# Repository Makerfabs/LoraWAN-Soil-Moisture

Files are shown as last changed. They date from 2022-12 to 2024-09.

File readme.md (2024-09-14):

# LoraWAN Soil Moisture

```c++
/*
Version:		V1.2
Author:			Vincent
Create Date:	2022/12/15
Note:
	2022/12/30	V1.2	:Update readme
	2022/12/16 	V1.1	:Fix adc3 read error.
*/
```


[toc]

# Makerfabs

[Makerfabs home page](https://www.makerfabs.com/)

[Makerfabs Wiki](https://wiki.makerfabs.com/)

# LoraWAN Soil Moisture
## Intruduce

Product Link ：[LoRaWAN Temperature/ Humidity/ Soil Moisture Sensor](https://www.makerfabs.com/lorawan-temperatur-humidity-soil-moisture-sensor.html) 

Wiki Link : [LoRaWAN Temperature/ Humidity Soil Moisture Sensor](https://wiki.makerfabs.com/LoRaWAN_Temperature_Humidity_Soil_Moisture_Sensor.html) 

This module monitor soil moisture via capacitive method, with waterproof coating, it avoids the corrosion problem that usually happens on cheap resistor-mode soil moisture sensor. There is also onboard AHT10 -air temperature/ humidity sensor, to monitor air status, proper for usage in the greenhouse. This module uses 3x AAA battery as power, with sleep current of 26uA and working current of 4mA, the average working time can be more than 1 year. (with 1-hour message interval, Class A ).

## Feature

- LoRaWAN Nodes, RA08H
- Soil Moisture Measurement based on capacitive Testing
- Low power: 7.1uA when sleeping/4mA in message sending turn around
- Onboard AHT10 sensor to monitor air temperature and air humidity
- Onboard Battery Voltage Measurement
- Full Open Source- all hardware and software open at GitHub
- Compatible with Arduino
- Supply power voltage: 4.7~3.5V

### Front:

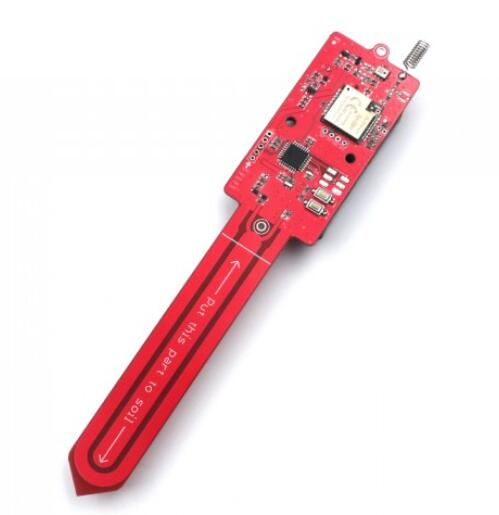
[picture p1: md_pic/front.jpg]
front


### Back:
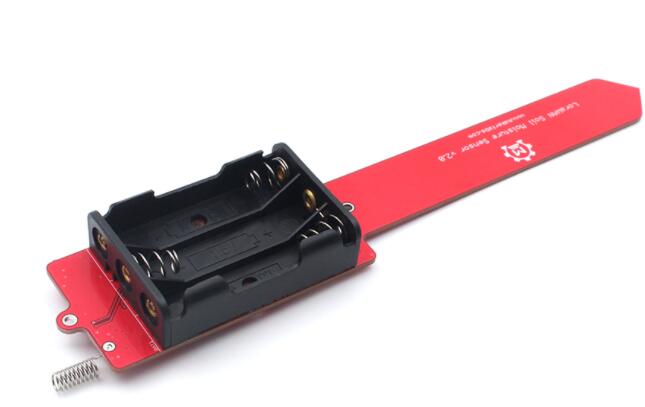
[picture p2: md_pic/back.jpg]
back


# Code

## Compiler Options

**If you have any questions，such as how to install the development board, how to download the code, how to install the library. Please refer to :[Makerfabs_FAQ](https://github.com/Makerfabs/Makerfabs_FAQ)**

- Open code with Arduino IDE
- Set Lorawan config in code.
- Upload codes, select "Arduino Pro or Pro Mini" and "3.3V 8MHz"

## Uploader

There is no USB socket or integrated serial port chip on some modules. But there are serial ports: VCC, GND, RX, TX, DTR. 

There are two ways to connect a serial port.

### MakerFabs CP2104 USB2UART

Product link : [CP2104 USB2UART](https://www.makerfabs.com/cp2104-usb-to-serial-converter.html)

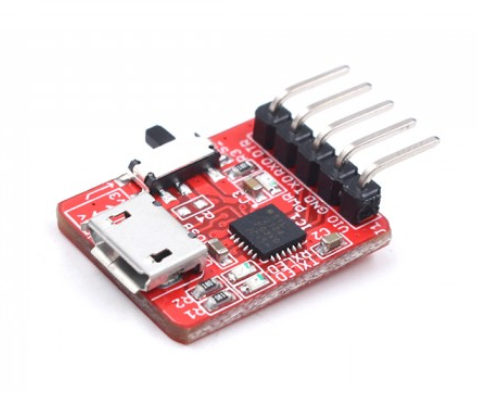
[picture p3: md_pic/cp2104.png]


This CP2104 USB to Serial Converter is super tiny, a highly-integrated USB-to-UART Bridge Controller providing a simple solution for updating and programming.

The serial port module has the same pin position as the makerfabs module with no USB port. So just plug it into the hole.

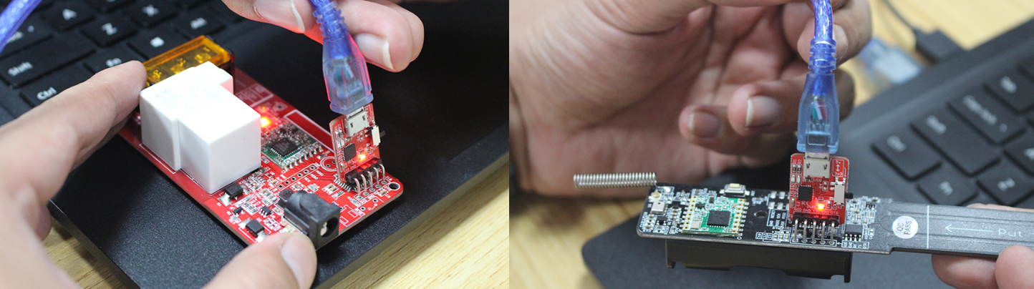
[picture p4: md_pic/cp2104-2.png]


The usage of usb cable is the same after that.

### CP2102 MODULES USB TO TTL

There are many common USB serial port modules on the market, which are basically connected in a common way.

| Makerfabs | USB To TTL |
| --- | --- |
| VCC | 3.3V |
| GND | GND |
| RX | TXD |
| TX | RXD |

## Testing file for manufacture

**moisture_test.ino**

This is a test demo. You can check all sensor, button, led and Lorawan.

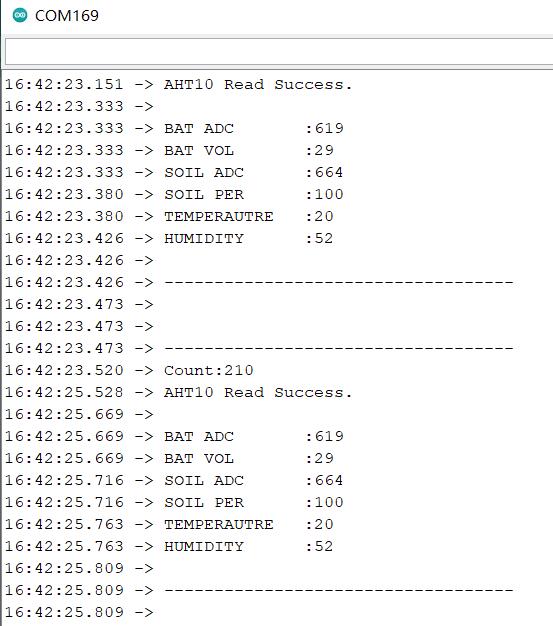
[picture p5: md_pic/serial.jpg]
serial


Change Lorawan config to yourself.

```c++
//config.h

#define DEVEUI "YOUR_DEVEUI"
#define APPEUI "YOUR_APPEUI"
#define APPKEY "YOUR_APPKEY"

```

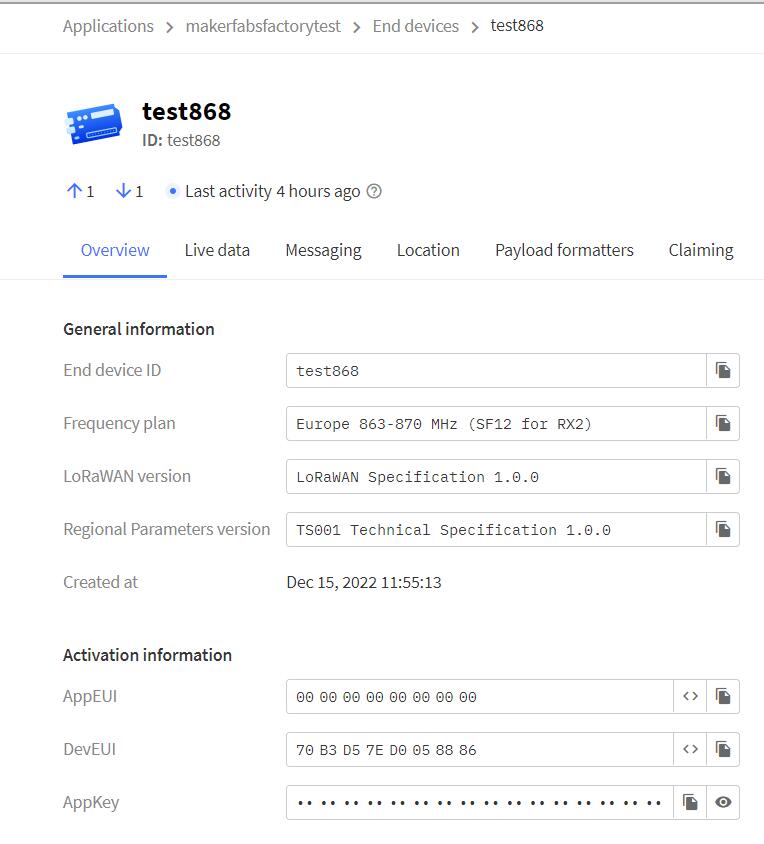
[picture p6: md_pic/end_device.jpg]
end_device


When hold on button, will send lorawan message to TTN.

```c++

```

## Firmware Frame

**mositure_lorawan**

This routine is expected to run on 3 AAA batteries for a year (once per hour).

Hibernation current 26ua, normal working current 4.7ma, peak emission 8.7ma.

The register is used to read the soil ADC and the battery voltage ADC. 

~~*There is a bug in the battery voltage ADC reading at present and it is being modified.*~~

Change Lorawan config to yourself.

Set sleep time, every watchdog sleep cycle nearly 8.5 s.

```c++
//Almost 1 hours
#define SLEEP_CYCLE 450
```

Lorawan sends data in the following ways:

```c++
    String temp = "AT+DTRX=1,2,8,";

    char data_str[80];
    sprintf(data_str, "%02x%02x%02x%02x", 
            (int)temperature, (int)humidity, soil_percent, bat_vol);
    temp = temp + data_str;
```

The corresponding parsing function for the thing network is as follows:

```javascript
function decodeUplink(input) {
  
  var temp = input.bytes[0]
  var humi = input.bytes[1]
  var adc = input.bytes[2]*256+input.bytes[3]
  var bat = input.bytes[4]/10
  var num = input.bytes[5] * 100 + input.bytes[6] 
  
  return {
    data:{
    //adc,
    //temp,
    //humi,
    //bat,
    //num,
    field1:adc,
    field2:temp,
    field3:humi,
    field4:bat,
    field5:num,
    },
    
  };
  
```

## Example

### 328p_at

Example for AT command test.

### adc_sleep

Tests whether ADC reads normally after MCU sleeps.

# Case

3D print case

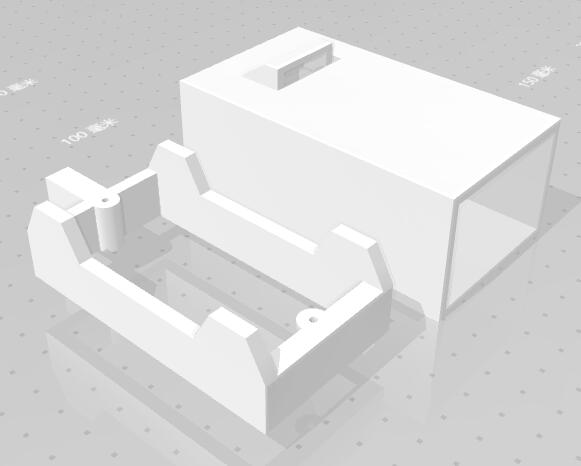
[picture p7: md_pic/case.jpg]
case


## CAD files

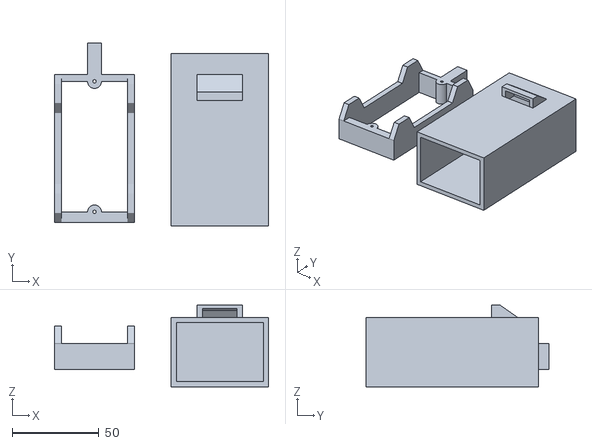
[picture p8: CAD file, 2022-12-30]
case/sensor_case.stl
123.0 x 105.0 x 47.0

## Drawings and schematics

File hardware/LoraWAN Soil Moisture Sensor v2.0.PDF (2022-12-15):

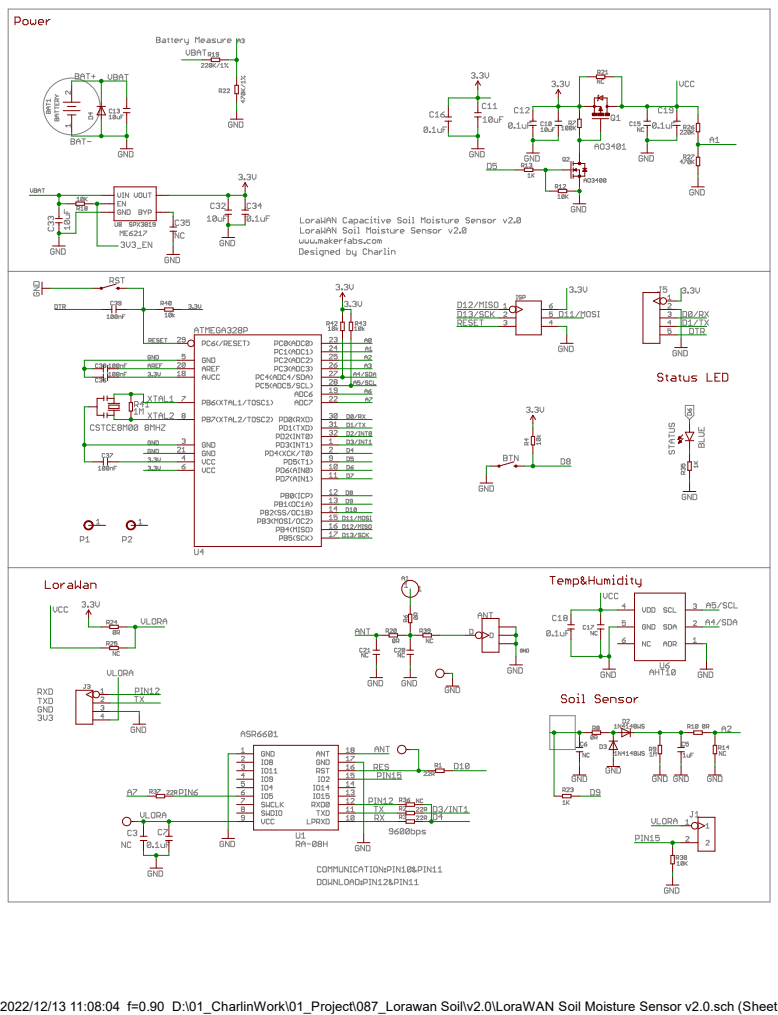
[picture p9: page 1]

2022/12/13 11:08:04 f=0.90 D:\01_CharlinWork\01_Project\087_Lorawan Soil\v2.0\LoraWAN Soil Moisture Sensor v2.0.sch (Sheet: 1/1)

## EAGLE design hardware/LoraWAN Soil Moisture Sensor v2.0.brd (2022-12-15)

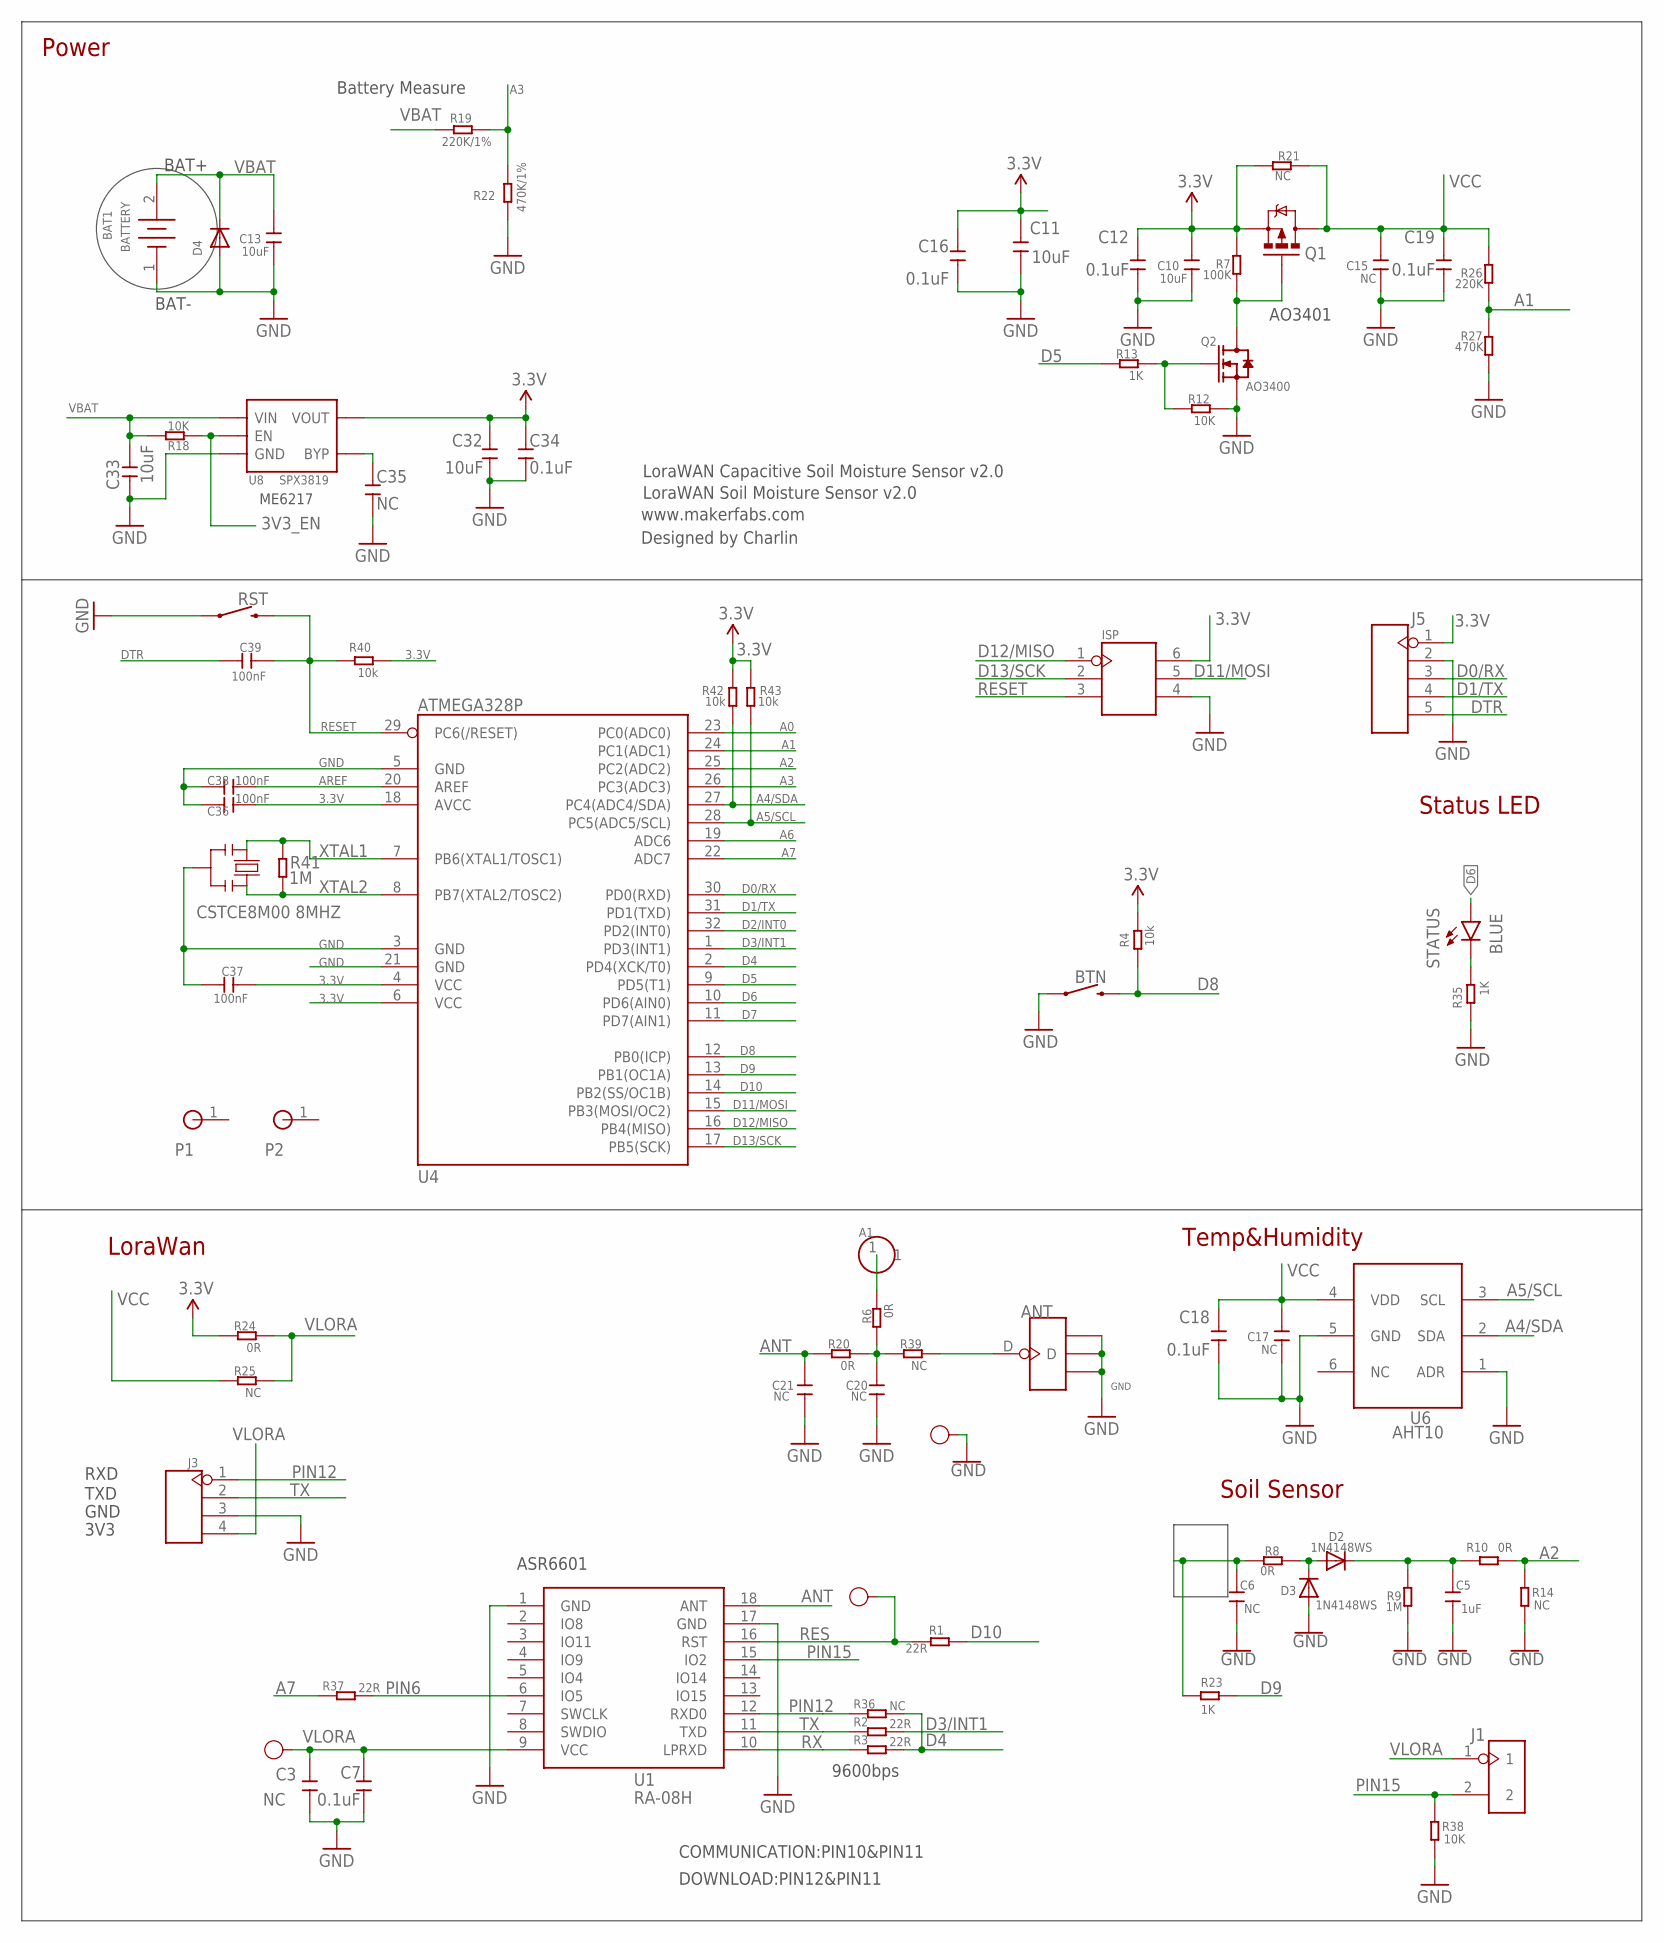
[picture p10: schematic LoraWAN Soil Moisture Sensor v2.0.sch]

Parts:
3V3: TEST-POINT'4545'; TP-D45MIL; PARTNO DNP
A1: HEADER-1P-50; 1P-100/50MIL
ANT: ANTENNA-U-FL; 4P-U-FL
BAT1: BATTERY
BTN: MOMENTARY-SWITCH-SPST-SMD-6.0X3.5MM; TACTILE_SWITCH_SMD_6.0X3.5MM
C3, C15, C17, C20, C21, C35: NC; 0603
C5: 1uF; DISCRETE_C0603
C6: NC; DISCRETE_C0603
C7, C12, C16, C18, C19, C34: 0.1uF; 0603
C10, C11, C13, C32, C33: 10uF; 0603
C36, C37, C38, C39: 100nF; 0603
D2, D3: 1N4148WS; SOD-323F
D4: DIODESOD-323F; SOD-323F
GND: TEST-POINT'4545'; TP-D45MIL
ISP: HEADER-2X3P-SMD; 2X3P-2.54-SMD
J1: HEADER-2P-2.0; 2P-2.0
J3: HEADER-4P-60/35MILROUND; 4P-65/35ROUND
J5: HEADER-5P-2.54; 5P-2.54
P1, P2: HOLE-P1-2.2; MTGNP1-220-1MM
Q1: MOSFET-PCHANNEL; SOT23-3
Q2: AO3400; DISCRETE_SOT23
R1, R2, R3, R37: 22R; R0603
R4, R40, R42, R43: 10k; R0603
R6, R8, R10, R20, R24: 0R; R0603
R7: 100K; R0603
R9, R41: 1M; R0603
R12, R18, R38: 10K; R0603
R13, R23, R35: 1K; R0603
R14, R21, R25, R36, R39: NC; R0603
R19: 220K/1%; R0603
R22: 470K/1%; R0603
R26: 220K; R0603
R27: 470K; R0603
RES: TEST-POINT'4545'; TP-D45MIL; PARTNO DNP
RST: MOMENTARY-SWITCH-SPST-SMD-6.0X3.5MM; TACTILE_SWITCH_SMD_6.0X3.5MM
STATUS: BLUE; LED-0603
U1: RA-08H
U4: ATMEGA328P; TQFP32
U6: AHT10; SMD6-127P-400L500W
U8: SPX3819; SOT23-5
Y1: CSTCE8M00 8MHZ; RESONATOR

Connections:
3.3V: C10.2, C11.2, C12.2, C16.2, C32.2, C34.2, C36.2, C37.2, ISP.6, J5.1, Q1.2 (S), R4.1, R7.2, R21.2, R24.2, R40.1, R42.1, R43.1, U4.4 (VCC), U4.6 (VCC), U4.18 (AVCC), U8.5 (VOUT)
3V3_EN: R18.2, U8.3 (EN)
A0: U4.23 (PC0(ADC0))
A1: R26.1, R27.2, U4.24 (PC1(ADC1))
A2: R10.2, R14.1, U4.25 (PC2(ADC2))
A3: R19.1, R22.2, U4.26 (PC3(ADC3))
A4/SDA: R42.2, U4.27 (PC4(ADC4/SDA)), U6.2 (SDA)
A5/SCL: R43.2, U4.28 (PC5(ADC5/SCL)), U6.3 (SCL)
A6: U4.19 (ADC6)
A7: R37.1, U4.22 (ADC7)
ANT: C21.2, R20.2, U1.18 (ANT)
AREF: C38.2, U4.20 (AREF)
D0/RX: J5.3, U4.30 (PD0(RXD))
D1/TX: J5.4, U4.31 (PD1(TXD))
D2/INT0: U4.32 (PD2(INT0))
D3/INT1: R2.2, U4.1 (PD3(INT1))
D4: R3.2, R36.2, U4.2 (PD4(XCK/T0))
D5: R13.2, U4.9 (PD5(T1))
D6: STATUS.A, U4.10 (PD6(AIN0))
D7: U4.11 (PD7(AIN1))
D8: BTN.2, R4.2, U4.12 (PB0(ICP))
D9: R23.2, U4.13 (PB1(OC1A))
D10: R1.2, U4.14 (PB2(SS/OC1B))
D11/MOSI: ISP.5, U4.15 (PB3(MOSI/OC2))
D12/MISO: ISP.1, U4.16 (PB4(MISO))
D13/SCK: ISP.2, U4.17 (PB5(SCK))
DTR: C39.1, J5.5
GND: ANT.GND1, ANT.GND2, ANT.GND3, BAT1.1, BTN.1, C3.1, C5.1, C6.1, C7.1, C10.1, C11.1, C12.1, C13.1, C15.1, C16.1, C17.1, C18.1, C19.1, C20.1, C21.1, C32.1, C33.1, C34.1, C35.1, C36.1, C37.1, C38.1, D3.A, D4.A, GND.T, ISP.4, J3.3, J5.2, Q2.2 (S), R9.1, R12.1, R14.2, R22.1, R27.1, R35.2, R38.2, RST.1, U1.1 (GND), U1.17 (GND), U4.3 (GND), U4.5 (GND), U4.21 (GND), U6.1 (ADR), U6.5 (GND), U8.2 (GND), Y1.2
unnamed: ANT.D, R39.1
unnamed: C6.2, R8.1, R23.1
unnamed: A1.1, R6.1
unnamed: Q1.1 (G), Q2.3 (D), R7.1
unnamed: D2.A, D3.C, R8.2
unnamed: Q2.1 (G), R12.2, R13.1
unnamed: C5.2, D2.C, R9.2, R10.1
unnamed: C20.2, R6.2, R20.1, R39.2
unnamed: C35.2, U8.4 (BYP)
unnamed: R35.1, STATUS.C
PIN6: R37.2, U1.6 (IO5)
PIN12: J3.1, R36.1, U1.12 (RXD0)
PIN15: J1.2, R38.1, U1.15 (IO2)
RES: R1.1, RES.T, U1.16 (RST)
RESET: C39.2, ISP.3, R40.2, RST.2, U4.29 (PC6(/RESET))
RX: R3.1, U1.10 (LPRXD)
TX: J3.2, R2.1, U1.11 (TXD)
VBAT: BAT1.2, C13.2, C33.2, D4.C, R18.1, R19.2, U8.1 (VIN)
VCC: C15.2, C17.2, C18.2, C19.2, Q1.3 (D), R21.1, R25.2, R26.2, U6.4 (VDD)
VLORA: 3V3.T, C3.2, C7.2, J1.1, J3.4, R24.1, R25.1, U1.9 (VCC)
XTAL1: R41.2, U4.7 (PB6(XTAL1/TOSC1)), Y1.1
XTAL2: R41.1, U4.8 (PB7(XTAL2/TOSC2)), Y1.3

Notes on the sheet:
LoraWAN Soil Moisture Sensor v2.0
www.makerfabs.com
LoraWAN Capacitive Soil Moisture Sensor v2.0
Designed by Charlin
BAT+
BAT-
AO3401
RXD
TXD
GND
3V3
ME6217
Battery Measure
Status LED
Temp&Humidity
Soil Sensor
LoraWan
Power
ASR6601
COMMUNICATION:PIN10&PIN11
DOWNLOAD:PIN12&PIN11
9600bps

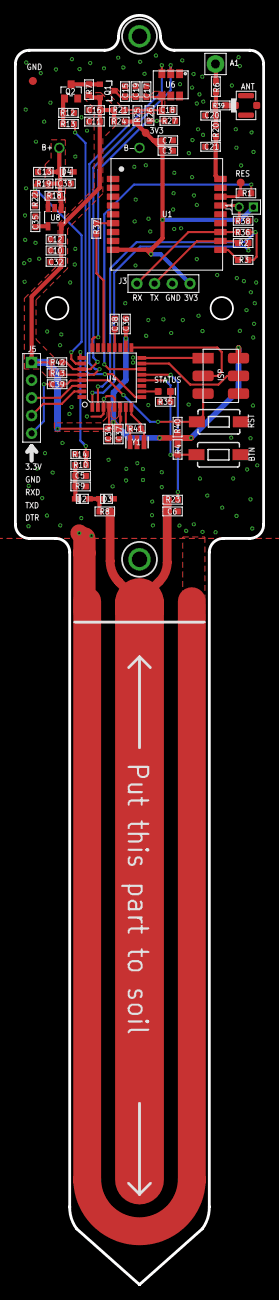
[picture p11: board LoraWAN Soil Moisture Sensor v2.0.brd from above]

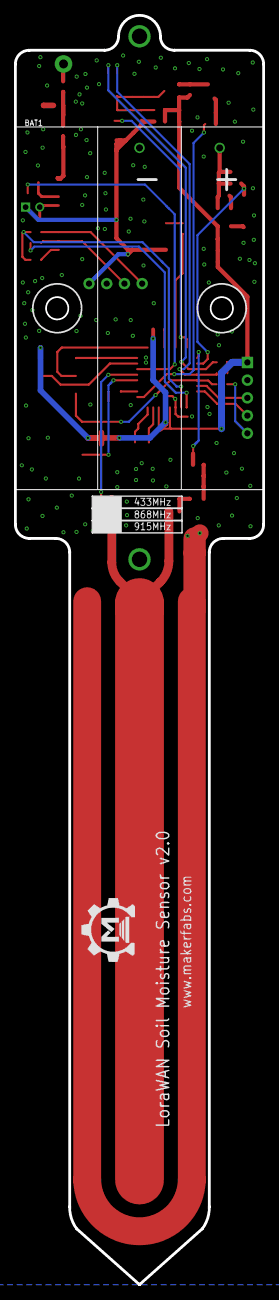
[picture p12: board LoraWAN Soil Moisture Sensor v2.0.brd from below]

Board: 2 copper layers, 35.6 x 182.0 mm, 80 parts (2 on the bottom side), 46 nets.

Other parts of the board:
U$7: MAKERFABS_0.3

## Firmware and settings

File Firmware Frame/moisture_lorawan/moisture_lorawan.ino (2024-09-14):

#include <Wire.h>
#include <avr/wdt.h>
#include <avr/sleep.h>
#include "I2C_AHT10.h"
#include <SoftwareSerial.h>

#include "config.h"

SoftwareSerial lorawan_serial(LORAWAN_TX, LORAWAN_RX);
AHT10 aht;

bool readSensorStatus = false;
int soil_adc = 0; // variable to store the value coming from the sensor
int soil_percent = 0;
int bat_adc = 0; // the voltage of battery
int bat_vol = 0;
int tx_count = 0;

float temperature = 0.0;
float humidity = 0.0;

int count = 0; // WDT count

void setup()
{
    pinMode(SENSOR_POWER_PIN, OUTPUT);
    pinMode(LORAWAN_RST, OUTPUT);
    // pinMode(LED_PIN, OUTPUT);

    // Ra08 restart
    digitalWrite(LORAWAN_RST, 0);
    delay(1000);
    digitalWrite(LORAWAN_RST, 1);

    lorawan_serial.begin(9600); // your esp's baud rate might be different
    log_init();

    delay(1000);
    log_out("---------------- Start----------------");
    delay(100);

    log_out("[First Task]");

    read_sensor();

    lorawan_init();

    while (lorawan_join())
    {
        send_lorawan();
        break;
    }

    log_out("[Task Over]");

    low_power();
}

void loop()
{
    wdt_disable();

    if (count > SLEEP_CYCLE) //(7+1) x 8S  450
    {

        log_out("[Task Start]");

        read_sensor();

        while (lorawan_join())
        {
            send_lorawan();
            break;
        }

        log_out("[Task Over]");

        // count init
        count = 0;
    }

    delay(50);
    low_power();
}

// ---------------------- Task -----------------------------
void read_sensor()
{
    digitalWrite(SENSOR_POWER_PIN, HIGH); // Sensor Power ON

    readSensorStatus = false;
    for (int i = 0; i < 3; i++)
    {

        if (readSensorStatus == false)
            readSensorStatus = aht_init();

        delay(500);
    }

    digitalWrite(SENSOR_POWER_PIN, LOW); // Sensor Power Off
    delay(100);

    pwn_init();
    delay(50);

    int ADC_O_1; // ADC Output First 8 bits
    int ADC_O_2; // ADC Output Next 2 bits

    // Soil Read
    // ADC2  AVCC as reference voltage
    ADMUX = _BV(REFS0) | _BV(MUX1);
    ADCSRA = _BV(ADEN) | _BV(ADPS1) | _BV(ADPS0);

    delay(50);

    soil_adc = 0;
    for (int i = 0; i < 3; i++)
    {
        // start ADC conversion
        ADCSRA |= (1 << ADSC);

        delay(10);

        if ((ADCSRA & 0x40) == 0)
        {
            ADC_O_1 = ADCL;
            ADC_O_2 = ADCH;

            soil_adc += (ADC_O_2 << 8) + ADC_O_1;
            ADCSRA |= 0x40;
        }
        ADCSRA |= (1 << ADIF); // reset as required
        delay(50);
    }
    soil_adc /= 3;

    // Battery Read
    // ADC3  AVCC as reference voltage
    ADMUX = _BV(REFS0) | _BV(MUX1) | _BV(MUX0);
    ADCSRA = _BV(ADEN) | _BV(ADPS1) | _BV(ADPS0);

    bat_adc = 0;
    delay(50);
    for (int i = 0; i < 3; i++)
    {
        // start ADC conversion
        ADCSRA |= (1 << ADSC);

        delay(10);

        if ((ADCSRA & 0x40) == 0)
        {
            ADC_O_1 = ADCL;
            ADC_O_2 = ADCH;

            bat_adc += (ADC_O_2 << 8) + ADC_O_1;
            ADCSRA |= 0x40;
        }
        ADCSRA |= (1 << ADIF); // reset as required
        delay(50);
    }
    bat_adc /= 3;

    // soil_adc = analogRead(A2);
    soil_percent = (int)((soil_adc - SOIL_ADC_WATER) / SOIL_ADC_UNIT);

    // bat_adc = analogRead(A3);
    bat_vol = (int)(bat_adc * 690.0 / 470.0 * 3300.0 / 1024.0);

    if (soil_percent > 100)
        soil_percent = 100;
    else if (soil_percent < 0)
        soil_percent = 0;

    bat_vol = bat_vol / 100;
}

// -------------------- Lorawan ---------------------------------

void sendData(String command, const int timeout)
{
    String response = "";

    log_out(command.c_str());
    lorawan_serial.println(command); // send the read character to the Serial

    long int time = millis();

    while ((time + timeout) > millis())
    {
        while (lorawan_serial.available())
        {
            char c = lorawan_serial.read(); // read the next character.

            if (c == '\n')
            {
                log_out(response.c_str());
                response = "";
            }
            else if (c == '\r')
                continue;
            else
                response += c;
        }
    }

    log_out(response.c_str());
}

int sendData_keyword(String command, const int timeout, String keyword)
{
    String response = "";

    log_out(command.c_str());
    lorawan_serial.println(command); // send the read character to the Serial

    long int time = millis();

    while ((time + timeout) > millis())
    {
        while (lorawan_serial.available())
        {
            char c = lorawan_serial.read(); // read the next character.

            if (c == '\n')
            {
                log_out(response.c_str());

                if (response.indexOf(keyword) != -1)
                {
                    return 1;
                }

                response = "";
            }
            else if (c == '\r')
                continue;
            else
                response += c;
        }
    }

    log_out(response.c_str());
    return 0;
}

// Only need set one time
void lorawan_init()
{
    sendData("AT", 3000);
    sendData("AT", 3000);

    char cmd[80];

    sprintf(cmd, "%s%s", "AT+CDEVEUI=", DEVEUI);
    sendData(cmd, AT_TIMEOUT);
    sprintf(cmd, "%s%s", "AT+CAPPEUI=", APPEUI);
    sendData(cmd, AT_TIMEOUT);
    sprintf(cmd, "%s%s", "AT+CAPPKEY=", APPKEY);
    sendData(cmd, AT_TIMEOUT);

    sendData("AT+CCLASS=0", AT_TIMEOUT);
    sendData("AT+CJOINMODE=0", AT_TIMEOUT);
}

int lorawan_join()
{
    // Wake Up Ra08
    sendData("AT", 2000);
    // Clean Serial
    sendData("AT", 2000);

    return sendData_keyword("AT+CJOIN=1,0,8,8", 30000, "Joined");
}

String create_tx_str()
{
    String temp = "AT+DTRX=1,2,12,";

    char data_str[80];
    // sprintf(data_str, "%02x%02x%02x%02x%04x", (int)temperature, (int)humidity, soil_percent, bat_vol, tx_count);
    sprintf(data_str, "%02x%02x%04x%02x%04x", (int)temperature, (int)humidity, soil_adc, bat_vol, tx_count);
    temp = temp + data_str;

    log_out(temp.c_str());

    return temp;
}

void send_lorawan()
{

    log_out_num("BAT ADC:", bat_adc);
    log_out_num("BAT VOL:", bat_vol);
    log_out_num("SOIL ADC:", soil_adc);
    log_out_num("SOIL PER:", soil_percent);
    log_out_num("TEMPERAUTRE:", (int)temperature);
    log_out_num("HUMIDITY:", (int)humidity);

    log_out_num("TX COUNT:", ++tx_count);

    sendData_keyword(create_tx_str(), 30000, "OK+SENT");
}

// --------------------- Device init --------------------------

bool aht_init()
{
    bool ret = false;
    Wire.begin();
    delay(5000);

    if (aht.begin() == false)
        log_out("AHT10 not detected. Please check wiring. Freezing.");
    else
    {

        while (1)
        {
            if (aht.available() == true)
            {
                temperature = aht.getTemperature();
                humidity = aht.getHumidity();
                ret = true;
                log_out("AHT10 Read Success.");
                break;
            }
            delay(1000);
        }
    }
    Wire.end();

    return ret;
}

void pwn_init()
{
    pinMode(PWM_OUT_PIN, OUTPUT);    // digitalWrite(PWM_OUT_PIN, LOW);
    TCCR1A = bit(COM1A0);            // toggle OC1A on Compare Match
    TCCR1B = bit(WGM12) | bit(CS10); // CTC, scale to clock
    OCR1A = 1;                       // compare A register value (5000 * clock speed / 1024).When OCR1A == 1, PWM is 2MHz
}

// --------------------- Watch dog ----------------------------------
void watchdog_init()
{
    // clear various "reset" flags
    MCUSR = 0;
    // allow changes, disable reset
    WDTCSR = bit(WDCE) | bit(WDE);
    WDTCSR = bit(WDIE) | bit(WDP3) | bit(WDP0); // set WDIE, and 8 seconds delay
    wdt_reset();                                // pat the dog
}

ISR(WDT_vect)
{
#if DEBUG_OUT_ENABLE
    // Serial.print("[Watch dog]");
    // Serial.println(count);
    if (count % 50 == 0)
        Serial.print(".");
#endif

    delay(100);
    count++;
    wdt_disable(); // disable watchdog
}

// -------------- Power Control --------------------------
void low_power()
{
    pinMode(PWM_OUT_PIN, INPUT);
    pinMode(A4, INPUT_PULLUP);
    pinMode(A5, INPUT_PULLUP);

    delay(50);

    // disable ADC
    ADCSRA = 0;

    watchdog_init();
    sleep_enable();
    set_sleep_mode(SLEEP_MODE_PWR_DOWN);
    noInterrupts();

    // turn off brown-out enable in software
    MCUCR = bit(BODS) | bit(BODSE);
    MCUCR = bit(BODS);
    interrupts();

    sleep_cpu();
    sleep_disable();
}

// ---------------------- Log ---------------------------

void log_init()
{
#if DEBUG_OUT_ENABLE
    Serial.begin(9600);
#endif
}

void log_out(const char *log)
{
#if DEBUG_OUT_ENABLE
    Serial.println(log);
#endif
}

void log_out_num(const char *log, int num)
{
#if DEBUG_OUT_ENABLE
    Serial.print(log);
    Serial.println(num);
#endif
}

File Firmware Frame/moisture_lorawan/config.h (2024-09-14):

// pin set
#define VOLTAGE_PIN A3
#define PWM_OUT_PIN 9
#define SENSOR_POWER_PIN 5
#define ADC_PIN A2

#define LORAWAN_TX 3
#define LORAWAN_RX 4
#define LORAWAN_RST 10

#define DEBUG_OUT_ENABLE 1

#define SOIL_ADC_WATER 550
#define SOIL_ADC_AIR 660
#define SOIL_ADC_UNIT ((SOIL_ADC_AIR - SOIL_ADC_WATER) / 100.0)

#define AT_TIMEOUT 3000

#define DEVEUI "70B3D57ED006A6A8"
#define APPEUI "0000000000000001"
#define APPKEY "93F151D5CFBE8AC4A0E5AE28497F747E"

#define SLEEP_CYCLE 450
// #define SLEEP_CYCLE 1

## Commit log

2022-12-15 Change File Name
    [LoraWAN Soil Moisture Sensor v2.0.brd, LoraWAN Soil Moisture Sensor v2.0.sch]
2022-12-16 Fix adc read bug.
    [adc_sleep.ino, moisture_lorawan.ino]
2022-12-30 Add 3dp case.
    [sensor_case.stl]
2023-01-04 Add tx count, fix test code bug.
    [moisture_lorawan.ino, moisture_test.ino]

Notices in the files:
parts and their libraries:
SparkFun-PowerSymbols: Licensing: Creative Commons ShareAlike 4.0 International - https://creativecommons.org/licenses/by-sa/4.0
